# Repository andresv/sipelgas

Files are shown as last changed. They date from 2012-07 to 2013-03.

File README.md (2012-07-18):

## Sipelgas

ANT based sensors using TI MSP430FR5728 microcontroller and Nordic Semiconductor nRF24AP2-1CH radiochip that runs ANT protocol stack.

## LICENSE
### Hardware
This work is licensed under version 3.0 of the Creative Commons CC-BY-SA license.
http://creativecommons.org/licenses/by-sa/3.0/

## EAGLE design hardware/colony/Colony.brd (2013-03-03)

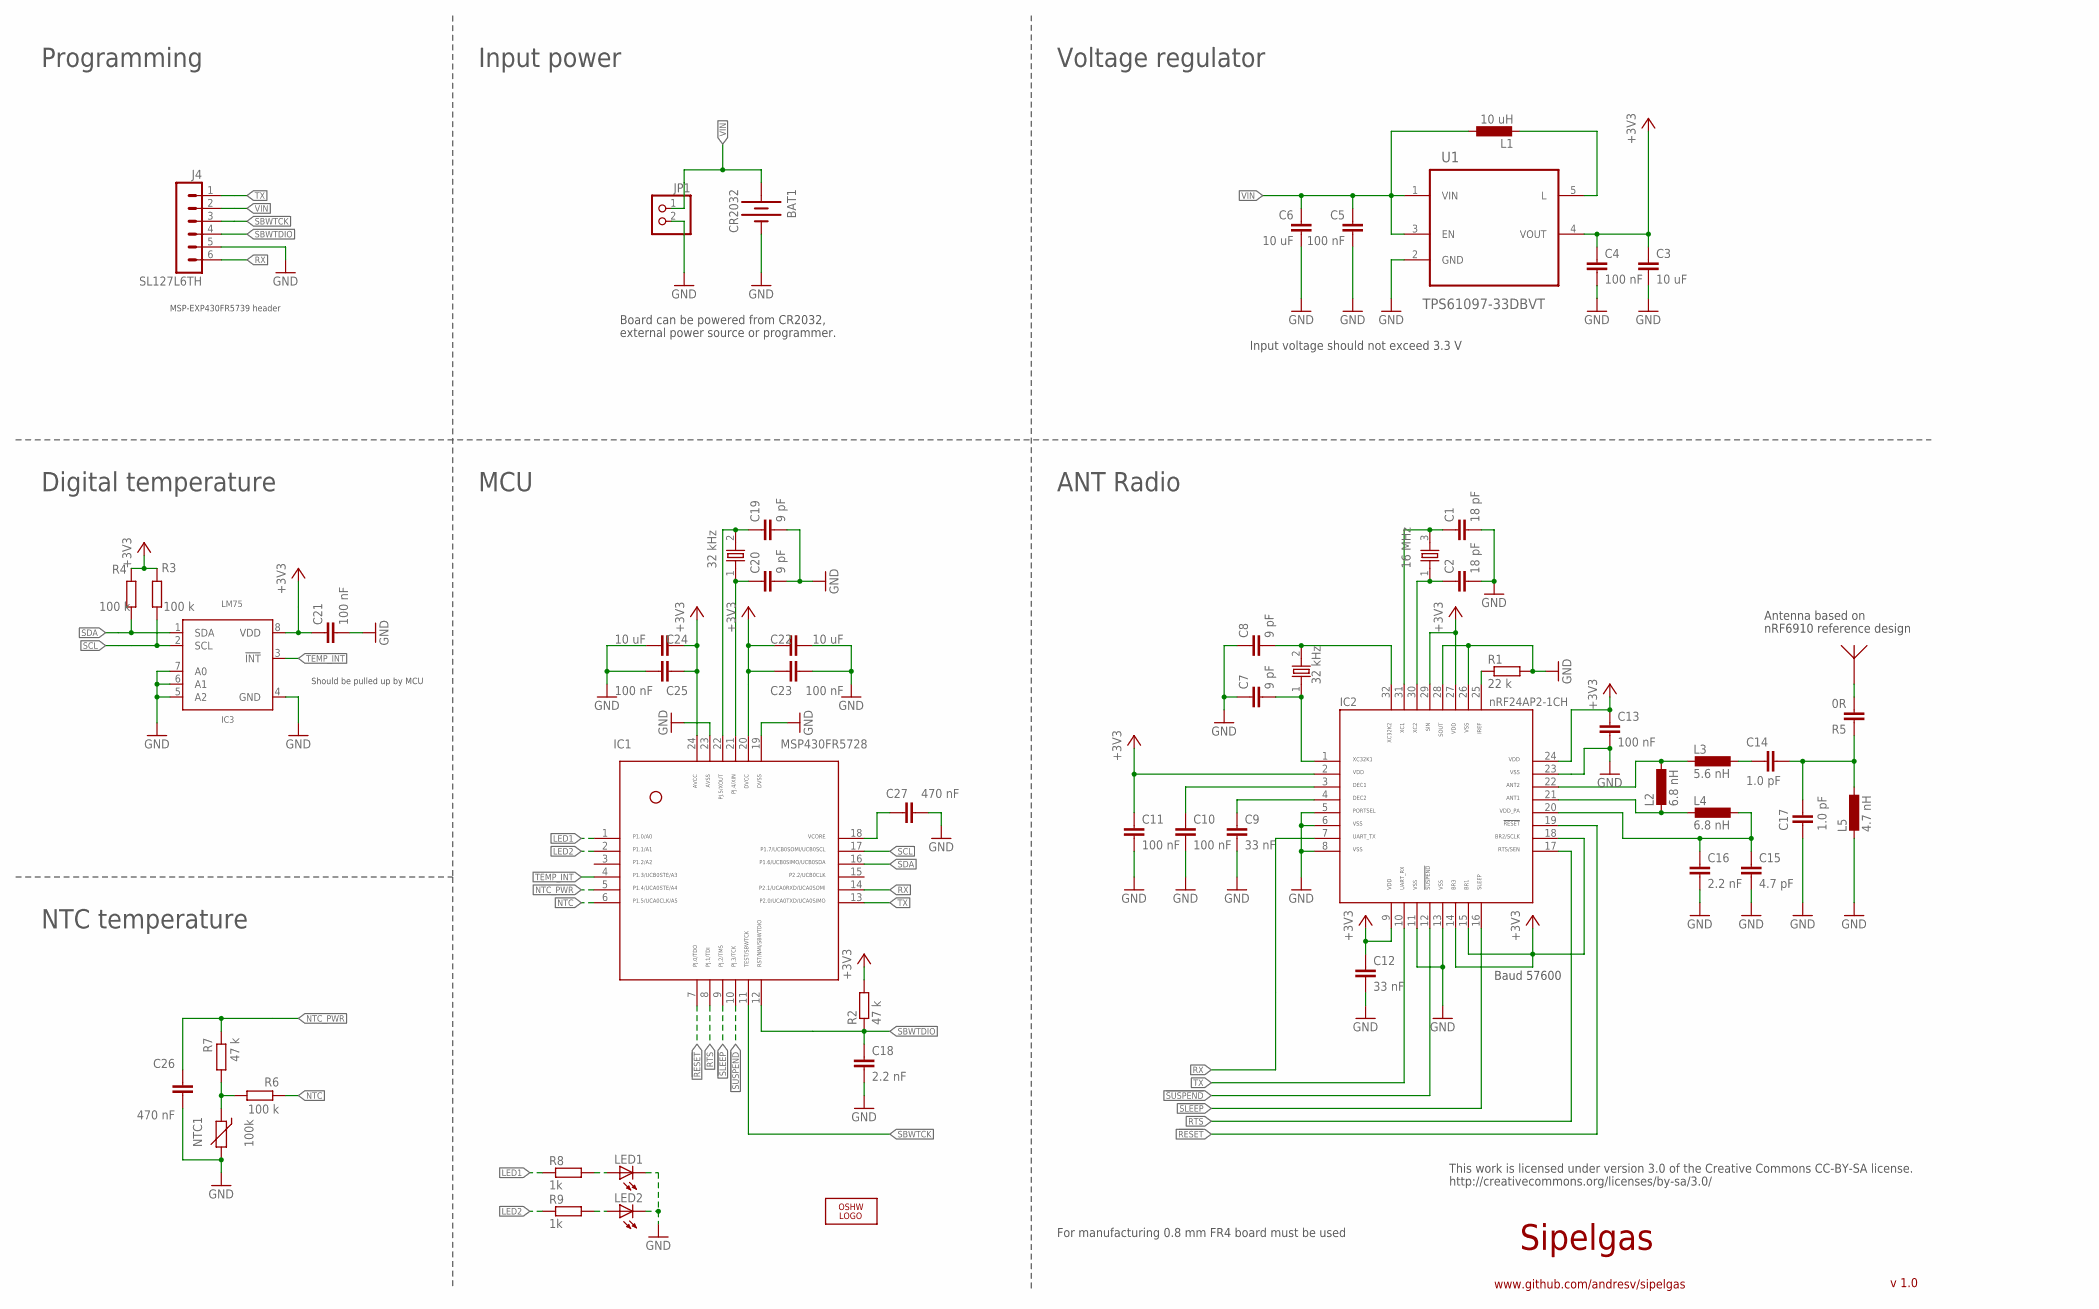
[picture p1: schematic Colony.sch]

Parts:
BAT1: CR2032; BATTCON_20MM
C1, C2: 18 pF; C0402
C3, C6, C22, C24: 10 uF; C0402
C4, C5, C10, C11, C13, C21, C23, C25: 100 nF; C0402
C7, C8, C19, C20: 9 pF; C0402
C9, C12: 33 nF; C0402
C14, C17: 1.0 pF; C0402
C15: 4.7 pF; C0402
C16, C18: 2.2 nF; C0402
C26, C27: 470 nF; C0402
IC1: MSP430FR5728; QFN-24
IC2: nRF24AP2-1CH; QFN-32
IC3: LM75; MSOP8
J4: SL127L6TH; SL127L6_MPE
JP1: PINHD-1X2; 1X02
L1: 10 uH; L0805
L2, L4: 6.8 nH; L0402
L3: 5.6 nH; L0402
L5: 4.7 nH; L0402
LED1, LED2: LEDCHIP-LED0603; CHIP-LED0603
LOGO1: OSHW_LOGO_6MILX0100-NT; OSHW_6X100_NOTEXT
NTC1: 100k; RS-2,5
Q1: 16 MHz; CTS402_3.2X2.5
Q2, Q3: 32 kHz; ABS07
R1: 22 k; R0402
R2, R7: 47 k; R0402
R3, R4, R6: 100 k; R0402
R5: 0R; C0201
R8, R9: 1k; R0402
U1: TPS61097-33DBVT; SOT95P280X145-5N
U$1: NRF6910-ANTENNA; NRF6910

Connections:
!RESET: IC1.7, IC2.19
!SLEEP: IC1.9, IC2.16
!SUSPEND: IC1.10, IC2.12
+3V3: C3.1, C4.1, C11.1, C12.1, C13.1, C21.1, C22.1, C23.1, C24.1, C25.1, IC1.20, IC1.24, IC2.2, IC2.9, IC2.14, IC2.15, IC2.18, IC2.24, IC2.27, IC2.29, IC3.8 (VDD), R2.2, R3.2, R4.2, U1.4 (VOUT)
ANT: C14.2, C17.1, L5.1, R5.1
GND: BAT1.2 (-), C1.2, C2.2, C3.2, C4.2, C5.2, C6.2, C7.1, C8.1, C9.2, C10.2, C11.2, C12.2, C13.2, C15.2, C16.2, C17.2, C18.2, C19.2, C20.2, C21.2, C22.2, C23.2, C24.2, C25.2, C26.2, C27.2, IC1.19, IC1.23, IC2.5, IC2.6, IC2.8, IC2.11, IC2.13, IC2.23, IC2.26, IC2.28, IC3.4 (GND), IC3.5 (A2), IC3.6 (A1), IC3.7 (A0), J4.5, JP1.2, L5.2, LED1.C, LED2.C, NTC1.2, R1.2, U1.2 (GND)
LED1: IC1.1, R8.1
LED2: IC1.2, R9.1
unnamed: C2.1, IC2.30, Q1.1
unnamed: C1.1, IC2.31, Q1.3 (2)
unnamed: L1.2, U1.5 (L)
unnamed: IC2.25, R1.1
unnamed: C9.1, IC2.4
unnamed: C7.2, IC2.1, Q3.1
unnamed: C8.2, IC2.32, Q3.2
unnamed: C10.1, IC2.3
unnamed: C20.1, IC1.21, Q2.1
unnamed: C19.1, IC1.22, Q2.2
unnamed: NTC1.1, R6.1, R7.1
unnamed: C27.1, IC1.18
unnamed: LED1.A, R8.2
unnamed: R5.2, U$1.P$1
unnamed: LED2.A, R9.2
unnamed: IC2.22, L2.1, L3.2
unnamed: IC2.21, L2.2, L4.2
unnamed: C15.1, C16.1, IC2.20, L4.1
unnamed: C14.1, L3.1
NTC: IC1.6, R6.2
NTC_PWR: C26.1, IC1.5, R7.2
RTS: IC1.8, IC2.17
RX: IC1.14, IC2.7, J4.6
SBWTCK: IC1.11, J4.3
SBWTDIO: C18.1, IC1.12, J4.4, R2.1
SCL: IC1.17, IC3.2 (SCL), R3.1
SDA: IC1.16, IC3.1 (SDA), R4.1
TEMP_INT: IC1.4, IC3.3 (!INT)
TX: IC1.13, IC2.10, J4.1
VIN: BAT1.1 (+), C5.1, C6.1, J4.2, JP1.1, L1.1, U1.1 (VIN), U1.3 (EN)

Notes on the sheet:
Sipelgas
www.github.com/andresv/sipelgas
Input voltage should not exceed 3.3 V
Board can be powered from CR2032,
Baud 57600
external power source or programmer.
ANT Radio
MCU
Digital temperature
NTC temperature
Programming
Input power
Voltage regulator
MSP-EXP430FR5739 header
Should be pulled up by MCU
Antenna based on
nRF6910 reference design
For manufacturing 0.8 mm FR4 board must be used
v 1.0
This work is licensed under version 3.0 of the Creative Commons CC-BY-SA license.
http://creativecommons.org/licenses/by-sa/3.0/

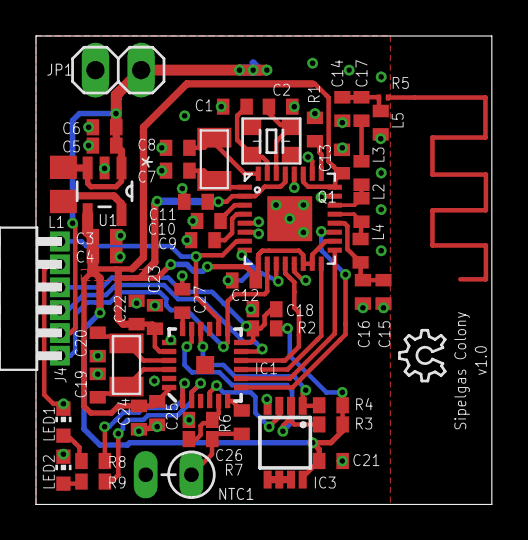
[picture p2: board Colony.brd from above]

Board: 2 copper layers, 25.3 x 26.0 mm, 56 parts (1 on the bottom side), 38 nets.

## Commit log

2012-07-18 Added first colony board schematic and layout.
    [Colony.brd, Colony.sch]
2013-03-03 Connected nRF24AP2-1CH pad to GND.
    [Colony.brd, Colony.sch]
